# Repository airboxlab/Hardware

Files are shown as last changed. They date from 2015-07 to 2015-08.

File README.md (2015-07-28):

# Airboxlab Hardware
Documentation, electronics and mechanical CAD for Airboxlab

* Consult Bills of Materials available in this repo, for the diferent parts needed.
* Assembly instructions available in this repo in [html](https://cdn.rawgit.com/airboxlab/Hardware/master/Assembly_Instructions/assembly_instructions.html).
* Firmware documentation is in the [wiki](https://github.com/airboxlab/Firmware/wiki).

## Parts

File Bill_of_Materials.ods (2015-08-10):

Airboxlab Bill of Materials
 | Sub-assembly | Ref schematics | Qty | Part Description | Part Value | Package | Seeed PN | Replacement policy | Manufacturer | Manufacturer Ref | Notes/Remarks | Distributor | Second distributor | Third distributor
 | Sensor_PCB v2.1 | IC1 | 1 | I2C slave MCU | ATTiny24 | SOIC-14 |  | Ask | Atmel | ATTINY24A-SS |  | http://www.digikey.fr/product-search/fr?k=attiny24A-SS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 | http://fr.mouser.com/ProductDetail/Atmel/ATTINY24A-SSU/
 |  | J2 | 1 | Grove connector top SMD female |  | SMD | 3470090P1 | Ask
 |  | C1,C2,C3 | 3 | Decoupling capa | 1uF | C0805 | 0100440P1 | Similar
 |  | R1 | 1 | Resistor array | 4x 10k | R1206-8 | 0040070P1 | Similar
 |  | Q1 | 1 | Low side switch MOSFET | NMOS | SOT-23 | 0440200P1 | Similar
 |  | S1 | 1 | VOC Sensor |  |  |  | No | AppliedSensor | IAQEngine
 |  | S2 | 1 | CO2 Sensor |  |  |  | Ask |  | MQ135
 | Main_PCB v2.2 | IC1 | 1 | Humidity and temperature sensor I2C | CC2D23 | QFN-8 |  | No | GE M&C / NovaSensor | CC2D23 |  | http://fr.mouser.com/ProductDetail/GE-MC-NovaSensor/CC2D23/
 |  | U4 | 1 | Accelerometer | MMA8453 | QFN-16 |  | Ask | Freescale Semiconductor | MMA8453QT |  | http://fr.farnell.com/freescale-semiconductor/mma8453qt/accelerometer-10-8bit-3axis-16qfn/dp/1842361 | http://www.digikey.fr/product-search/fr?x=-1307&y=-73&lang=fr&site=fr&KeyWords=MMA8453QT
 |  | U2 | 1 | MCU with ADC, I2C, UART and USB | ATMega32u4 | QFN-44 |  | Ask | Atmel | ATMEGA32U4-MU |  | http://www.digikey.fr/product-detail/fr/ATMEGA32U4-MU/ATMEGA32U4-MU-ND/1914603 | http://fr.mouser.com/ProductDetail/Atmel/ATMEGA32U4-MU/?qs=sGAEpiMZZMvqv2n3s2xjsYzXfq0AWv1CDyO98lAu02M%3d
 |  | X1 | 1 | Crystal oscillator | 16MHz | QFN-2 | 0500290P1 | Similar
 |  | C4,C5 | 2 | Crystal oscillator capa | 8pF | C0603 |  | Similar |  | - |  | whatever | http://fr.farnell.com/jsp/search/productdetail.jsp?id=1759051&Ntt=1759051
 |  | U3 | 1 | USB ESD protection |  | SOT-23-6 |  | Ask | NXP Semiconductors | IP4220CZ6,125 |  | http://fr.farnell.com/nxp/ip4220cz6/esd-protection-dual-usb-2-0-6tsop/dp/1506629 | http://www.digikey.fr/scripts/DKSearch/dksus.dll?Detail&itemSeq=137462905&uq=635163209385322191
 |  | R4,R5 | 2 | USB resistors | 22R | R0603 | 0010010P1 | Similar
 |  | J1 | 1 | USB Micro plug |  | SMD | 3400150P1 | Similar
 |  | U1 | 1 | Battery charger chip |  | DFN-8 | 1320040P1 | Ask
 |  | J2 | 1 | Battery connector |  | THT | 3410070P1 | Ask |  |  |  |  | http://www.digikey.fr/product-search/fr?WT.z_header=search_go&lang=fr&site=fr&x=0&y=0&formaction=on
 |  | R1,R15,R16 | 3 | Rset, I2C pull ups | 3.6k 1% | R0603 |  | Similar |  | - |  | whatever | http://fr.mouser.com/Search/ProductDetail.aspx
 |  | (K1) | 0 | Reset button |  |  | 3100010P1 | Similar
 |  | L2,L5 | 2 | ferrite bead | 120R 500mA | L0603 | 0040070P1 | Similar
 |  | F1 | 1 | Fuse 1000mA | 1000mA | R1206 | 0900020P1 | Similar
 |  | IC3 | 1 | step-up reg 5V | 5V, >=500mA | TSOP-5 |  | Ask | ON Semiconductor | NCP1450ASN50T1G |  | http://fr.farnell.com/on-semiconductor/ncp1450asn50t1g/convertisseur-dc-dc-step-up-5-0v/dp/1460676
 |  | Q1,Q3 | 2 | MOSFET N channel | NMOS | SOT-23 | 0440200P1 | Similar
 |  | D1 | 1 | Shottky diode | 5A | SMB | 0310130P1 | Similar
 |  | L1 | 1 | Inductor | 10uH |  |  | Similar | Bourns | SRU8043-100Y |  | http://fr.farnell.com/bourns/sru8043-100/inductance-de-puissance-blindee/dp/1362119
 |  | C14,C15,C28,C29,C31 | 5 | Capa Tantalum | 100uF | AVX-C | 0130170P1 | Similar
 |  | U5 | 1 | 3.3V regulator | 3.3V, 1A | SOT-89 | 1310120P1 | Similar
 |  | U6 | 1 | Wifi module | CC3000 | QFN |  | No | Texas Instruments | CC3000MOD |  | http://www.digikey.fr/product-search/fr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 | http://fr.mouser.com/ProductDetail/Texas-Instruments/CC3000MOD/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
 |  | ANT1 | 1 | Chip Antenna 2,4GHz | 2,4GHz |  |  | No | Johanson Technology Inc | 2450AT42A100E |  | http://fr.farnell.com/johanson-technology/2450at42a100e/antenne-2-4ghz/dp/2148522 | http://fr.mouser.com/ProductDetail/Johanson/2450AT42A100E/ | http://www.digikey.com/product-detail/en/2450AT42A100E/712-1007-1-ND/1560836
 |  | Q2,Q4,Q5,Q6,Q7 | 5 | Drivers for LEDs, P-channel MOSFET | PMOS | SOT-23 | 0440210P1 | Similar
 |  | D3,D4 | 2 | RGB Led |  | THT |  | Ask | Kingbright Company LLC | WP154A4SUREQBFZGW |  | http://fr.mouser.com/ProductDetail/Kingbright/WP154A4SUREQBFZGW/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
 |  | JP2 | 1 | GP2Y cable connector top insertion | 6 pin | THT |  | Ask | JST | B6B-ZR (LF)(SN) |  | http://www.digikey.fr/product-detail/fr/B6B-ZR(LF)(SN)/455-1661-ND/926568 | http://fr.farnell.com/jst-japan-solderless-terminals/b6b-zr-lf-sn/embase-entree-sup-6-voies/dp/9491805
 |  | R7,R8,R9,R10,R11,R12 | 6 | resistor for LEDs | 75R | R0603 | 0010220P1 | Similar |  |  |  |  | http://fr.mouser.com/ProductDetail/Vishay-Dale/CRCW060375R0FKEA/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
 |  | J3 | 1 | Grove connector top SMD female |  |  | 3470090P1 | Ask
 |  | D2,D5,D6 | 3 | Shottky / Flyback diode | 1A | SOD-123 | 0390030P1 | Similar |  |  |  |  | http://fr.mouser.com/ProductDetail/ON-Semiconductor/MBR130LSFT1G/
 |  | JP3 | 1 | Connector for Fan |  | THT |  | Ask | JST | B2B-XH-A (LF)(SN) |  | http://fr.farnell.com/jst-japan-solderless-terminals/b2b-xh-a-lf-sn/embase-male-vertical-2-voies/dp/1516276 | http://www.digikey.com/product-detail/en/B2B-XH-A%20(LF)(SN)(P)/455-2247-ND/1651045
 |  | C1,C2,C12,C13,C16,C17,C21 | 7 | Capa | 10uF | C0805 | 0100080P1 | Similar
 |  | C3,C6,C7,C8,C9,C10,C11,C19,C20,C23 | 10 | Capa | 1uF | C0603 | 0100340P1 | Similar
 |  | C18,C22,C24,C25,C26,C27 | 6 | Capa | 0,1uF | C0603 | 0100020P1 | Similar
 |  | S1 | 1 | ON/OFF switch |  | THT |  | Ask | C & K COMPONENTS | OS102011MA1QN1 |  | http://fr.farnell.com/c-k-components/os102011ma1qn1/emission-laterale-commutateur-spdt/dp/1201431
 |  | R2,R6,R13,R14 | 4 | Pull up/ pull down / voltage dividers | 10k x4 | R1206-8 |  | Similar |  | - |  | whatever | http://fr.mouser.com/ProductDetail/CTS-Electronic-Components/742C083473JP/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
 |  | (R3),R17,(R18) | 1 | Temp sensor power select, ([ALT]short 5V_switched and 5V_dirty) | 0R | R0603 |  | Similar |  | - |  | whatever
 |  | R19 | 1 | Isolation resistor for ADC | 100k | R0603 |  | Similar |  | - |  | whatever
 | GP2Y cable |  | 2 | Housing |  |  |  | No | JST | ZHR-6
 |  |  | 12 | Contact |  |  |  | No | JST | SZH-002T-P05 or SZH-003T-P05
 |  |  | 6 | Wire | 26 to 32 AWG, smaller the better |  |  | Similar
 |  |  |  | The GP2Y cable is straight (pin 1 is connected to pin 1) and flat (wires are not twisted). Both ends have the same connector.
 |  |  |  | Length from end of connector to end of connector : 33mm +/- 5mm
 |  |  |  | Preferably ribbon if possible
 |  |  |  | No requirement on wire colors
 | Grove Cable |  | 2 | Housing | buckled |  |  | Ask
 |  |  | 8 | Contact | like Grove cables |  |  | Similar
 |  |  | 4 | Wire | like Grove cables |  |  | Similar
 |  |  |  | The Grove Cable is straight (pin 1 is connected to pin 1) and flat (wires are not twisted). Both ends have the same connector.
 |  |  |  | Length from end of connector to end of connector : 135mm +/- 5mm
 |  |  |  | No requirement on wire colors
 | Enclosure | Cylinder_v13.igs | 1 | Tube |  |  |  | Ask
 |  | Top_plate.igs | 1 | Top plate |  |  |  | Ask
 |  | Bottom_part.stl | 1 | Bottom part |  |  |  | Ask | Sculteo / Shapeways |  | white strong and flexible | http://www.shapeways.com/product/HX6P2HMSU/airboxlab-pusher?li=user-profile&optionId=15531137
 |  | Pusher.stl | 2 | Pusher |  |  |  | Ask | Sculteo / Shapeways |  | white strong and flexible | http://www.shapeways.com/product/XN6GGS49G?li=user-profile&optionId=15530376
 |  | Top_cap.stl | 1 | Top cap |  |  |  | Ask | Reprap |  | white ABS / PLA
 |  | All_parts_but_bottom.svg | 1 | All laser cutted part |  |  |  | Ask | Lasercut |  | clear PMMA
 |  | Bottom_plate_white.svg | 1 | Bottom plate |  |  |  | Ask | Lasercut |  | white PMMA
 |  |  | 4 | Rubber feets |  |  |  | Similar | 3M | SJ5382 | clear | http://www.by-pixcl.com/3m-butees-adhesives-bumpon,fr,8,181.cfm
 |  |  | 4 | Bottom screws |  |  |  | Similar |  |  |  | http://www.visseriefixations.fr/plastite-tf-pozi-3x10-z-blanc.html
 |  |  | 4 | Side plates screws |  |  |  |  |  |  |  | http://www.visseriefixations.fr/voir-platcbh02-2-008zn.html
 |  |  | 4 | PCB & Pusher screws |  |  |  |  |  |  |  | http://www.visseriefixations.fr/tcbl-pozi-m2x6-z-blanc-din-7985.html

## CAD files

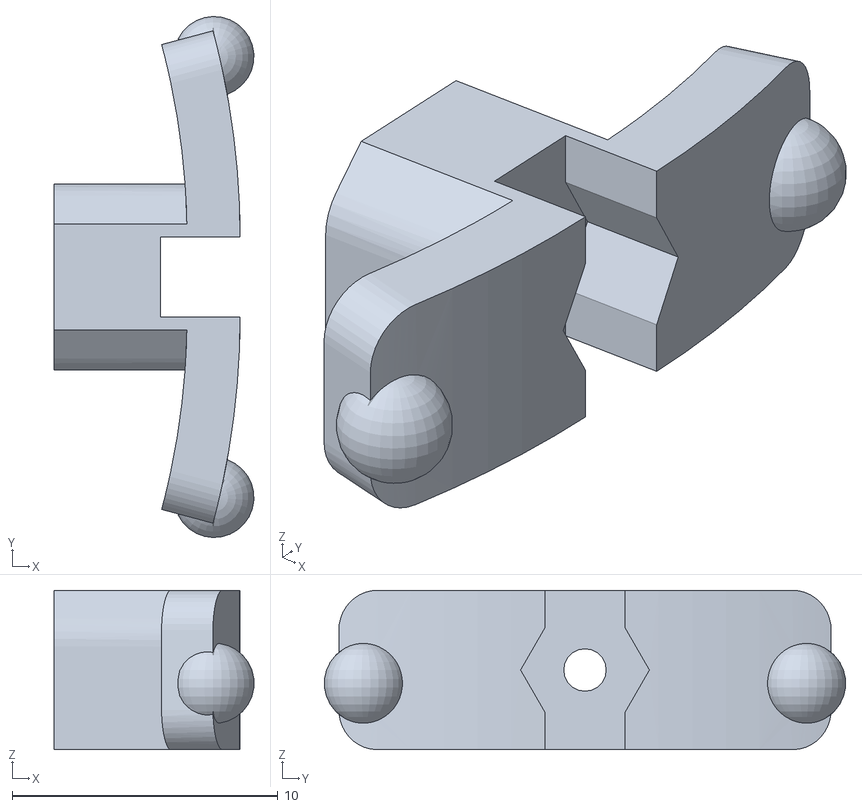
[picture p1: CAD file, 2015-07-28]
Mechanical_CAD/3D_printed/Pusher.stl
7.52 x 19.6 x 6.00

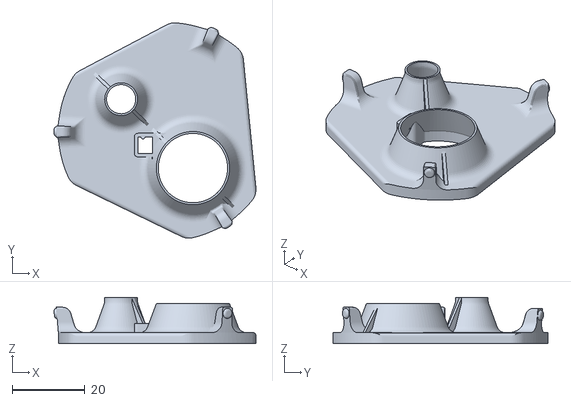
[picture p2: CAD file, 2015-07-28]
Mechanical_CAD/3D_printed/Top_cap.stl
55.4 x 59.1 x 12.7

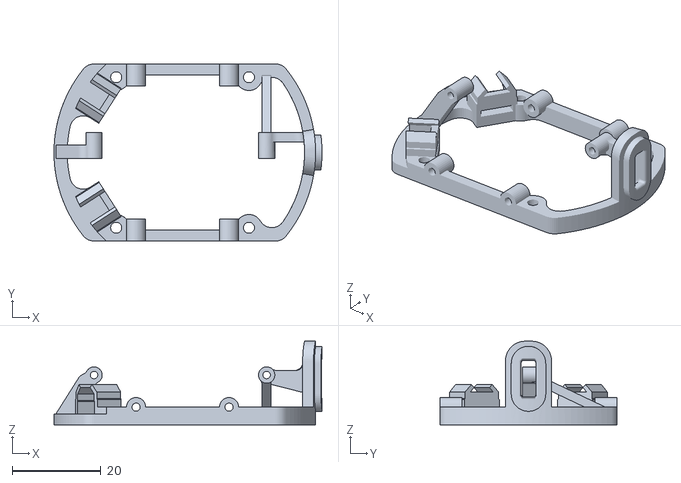
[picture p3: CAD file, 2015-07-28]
Mechanical_CAD/3D_printed/Bottom_part.stl
60.5 x 40.0 x 18.9

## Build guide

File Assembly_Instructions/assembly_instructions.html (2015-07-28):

Assembly Instructions

Airboxlab – Indoor air quality monitor (http://airboxlab.foobot.io)

This work by Airboxlab S.A. (http://airboxlab.com) is licensed under CERN OHL v. 1.2 (http://ohwr.org/cernohl).

Index table

1 Introduction

2 Required tools and supplies

2.1 Tools

2.2 Supplies

3 Prepare parts

3.1 Top_cap

3.2 Bottom_part

3.3 Pushers

3.4 Bottom_cap

4 Assembly steps

# 1 Introduction

This document describes Airboxlab indoor air quality manual step by step. It mandatory to follow the instruction in the described order for a compelling result.

Part names that this document refers to match the ones of the mechanical CAD.

# 2 Required tools and supplies

## 2.1 Tools

- Secondary M2 tap
- Small electric screw driver
- Pozidrive #1 screw bit
- Small Pozidrive #1 screw driver with a rod no lager than 3mm. Alternate: flat 2mm screw driver.
- Scalpel with pointed sharp ending blade
- Flat elongated pliers (no teeth) to handle connectors
- 6mm metal drill bit
- Pair of cisors
- Wire cutters
- Glue gun, No silicone based glue (fumes will damaged sensors)
- Drill Press

## 2.2 Supplies

Quantity to assemble one unit.

- 4x oval head machine screws POZI 2x6mm
- 4x thermoplastic domed head screws POZI 2.2x8mm
- 4x countersunk flathead thermoplastic screws POZI 3x10mm
- 2x Zip-tie 2.5x200mm
- 4x transparent silicone pads
- Electrical tape (~ 25cm)
- Transparent office tape (~ 15cm)
- Double-sided tape (~ 2cm)

# 3 Prepare parts

## 3.1 Top_cap

- Check hole in top cap to insert pin, correct hole with scalpel if necessary. Add a glue blob on each side of the pin.
   

## 3.2 Bottom_part

- Optional if the 2 POZI M2x6 do not hold when using the electrical screw driver: M2 tapping the two holes for the PCB.

## 3.3 Pushers

- Optional if the 2 POZI M2x6 do not hold when using the electrical screw driver: M2 tapping the two holes.
- Screw an M2x6 screw from the side with the fins until flush on the flat side:



## 3.4 Bottom_cap

- Countersink 4 holes with drill 6mm metal, plastic film side, of sufficient depth so that POZI 3x10 screw heads are fully embedded:
  
- Deburring with scalpel if necessary.

# 4 Assembly steps

1. Prepare parts (see 3).
2. Glue a piece of electrical tape over the battery, on the side where there is nothing written.
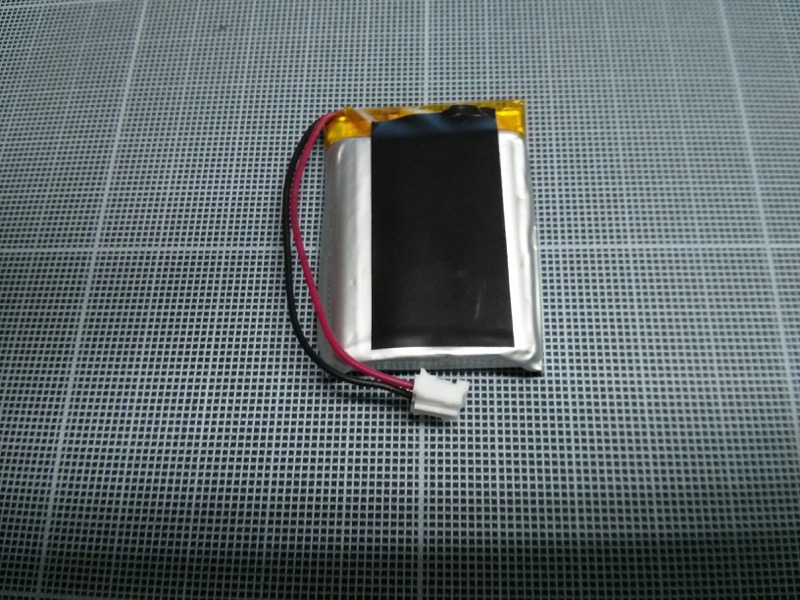
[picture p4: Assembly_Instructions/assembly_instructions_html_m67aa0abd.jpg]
  
3. Attach the battery on the side_plate with electrical tape, making sure of the orientation:
- Side of the battery with electrical tape is against side_plate.
- Battery is about 5mm above the bottom of the side_plate holes.
- Battery's wire comes down on the same side that the notches for the wires.

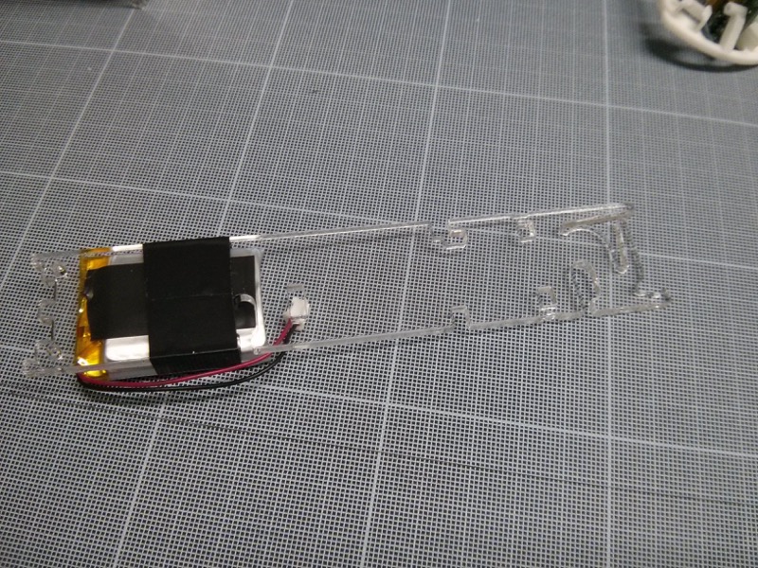
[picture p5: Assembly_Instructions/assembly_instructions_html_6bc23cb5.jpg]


3. Screw Main_PCB on bottom_part with 2 POZI M2x6 screws
  
4. Insert the two pushers in there notches in bottom_part.
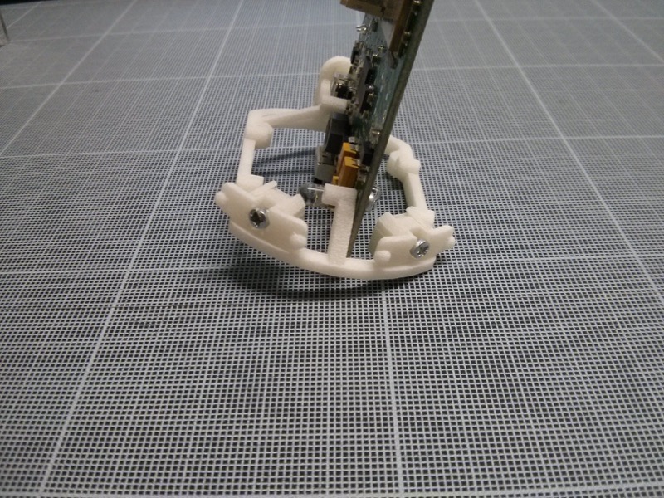
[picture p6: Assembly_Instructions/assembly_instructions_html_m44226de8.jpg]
  
5. Attach the fan and its two supports with two zip-tie (all together this is the top cross_section of airboxlab). Make sure of the orientation of parts: fan airflow direction, fan wire and zip-tie.
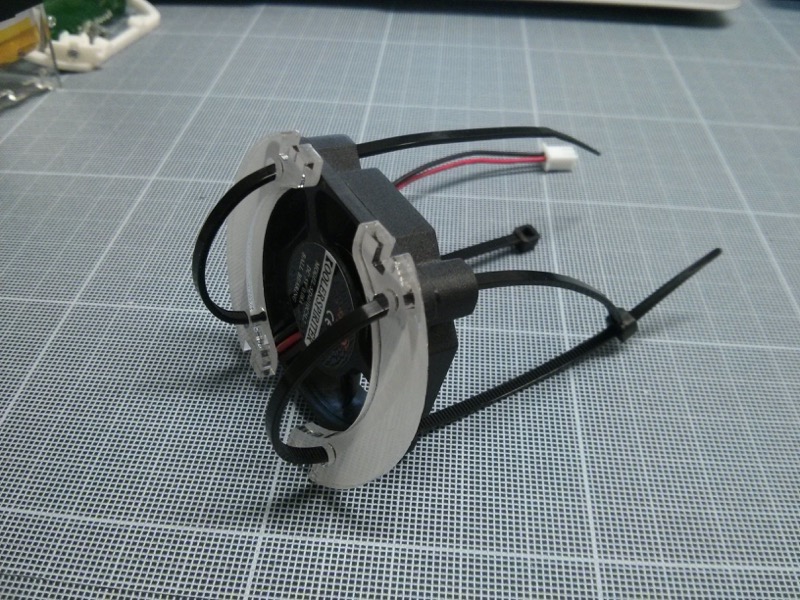
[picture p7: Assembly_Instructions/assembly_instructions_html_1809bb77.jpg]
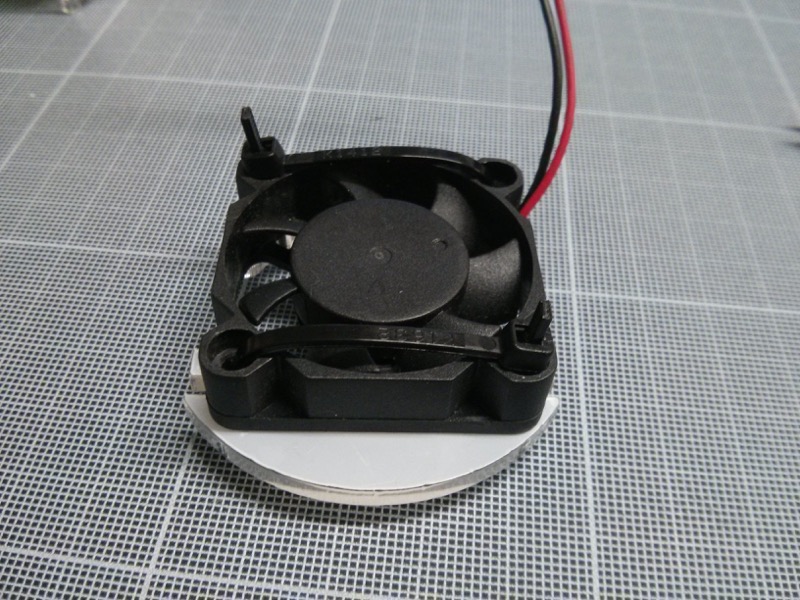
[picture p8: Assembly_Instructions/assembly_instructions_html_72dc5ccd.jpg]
   
6. Glue GP2Y on middle cross_section. Use a tool to precisely align it, if alignment is wrong it won't enter properly.
  
7. Connect GPY2 cable in the sensor then into Main_PCB.
  
8. Insert the assembly consisting of Main_PCB + bottom_part in the groove of the bottom cross_section. Check alignment with bottom_part: the sides of bottom_part must be aligned with sides of the cross_section.
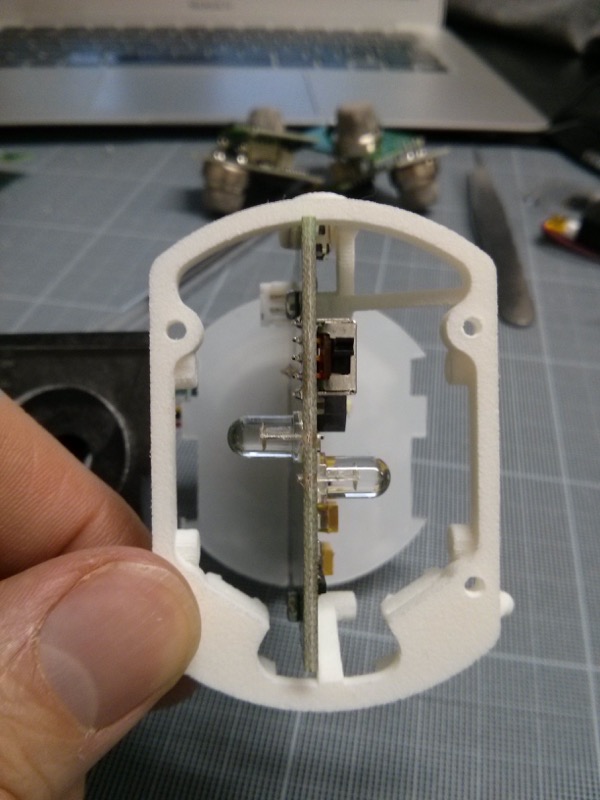
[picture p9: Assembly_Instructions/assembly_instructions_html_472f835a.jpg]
   
9. Assemble the 3 cross_sections on side_plate to which is attached the battery, starting with the one with the fan.
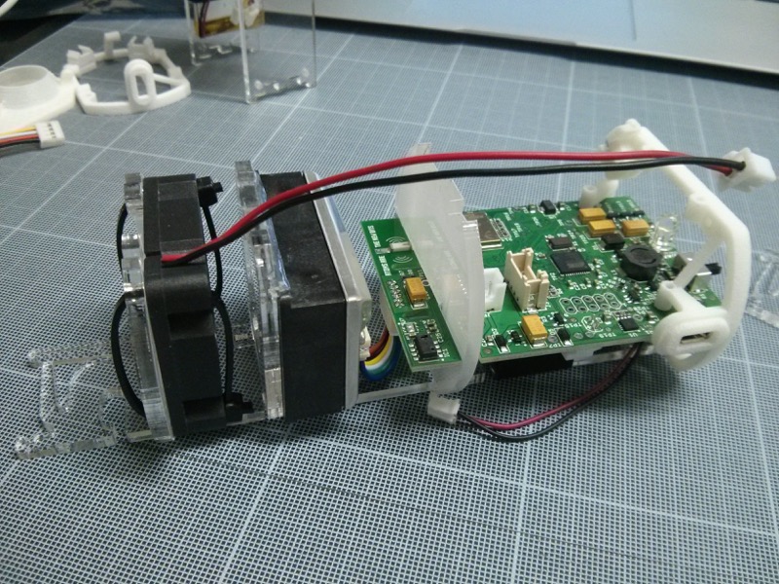
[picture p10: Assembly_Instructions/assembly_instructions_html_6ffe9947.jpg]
  
10. Place the second side_plate over the whole assembly. Both side_plates must be oriented so as to be superimposed. Check that the fan cable goes well in his small notch at the middle cross_section.
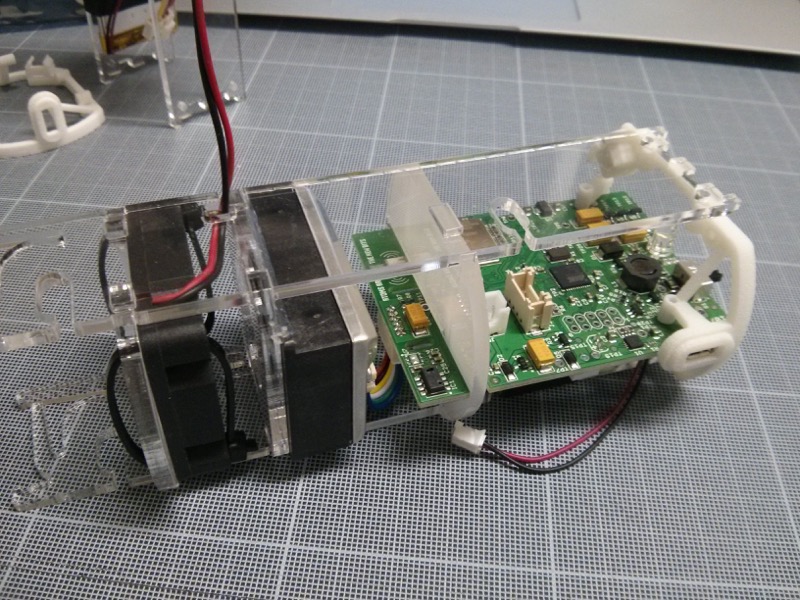
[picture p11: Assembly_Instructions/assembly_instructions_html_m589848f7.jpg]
  
11. Check that the sections are fully engaged, especially the middle one.
12. Put a strip of electrical tape (> = 16.5 cm) around the fan and the middle section:
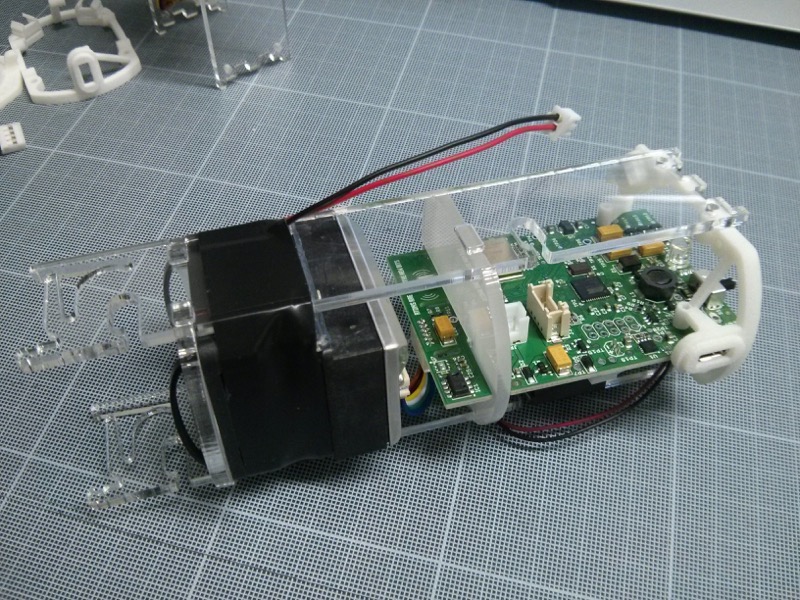
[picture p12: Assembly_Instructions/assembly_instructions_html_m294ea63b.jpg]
  
13. Connect Grove cable on Sensor_PCB.
14. Clip Sensor_PCB in the side plates and pass Grove cable into its top notch.
  
15. Place fan cable then Grove cable into the bottom cable notch.
16. Connect the fan cable in the Main_PCB using flat pliers.
17. Plug the cable into the Grove Main_PCB using flat pliers.
18. Pull excess wire with pliers so that they are snug to the side_plate.
19. Tape both cables on side_plate (~ 6cm).
  
20. Ensure that Main_PCB is totally engaged in the groove of cross_section, so that the edge of the PCB with T/RH sensor is flush along the cross_section.
21. Screw the side_plates to the bottom_part with 4 thermoplastic POZI 2.2x8mm screws.
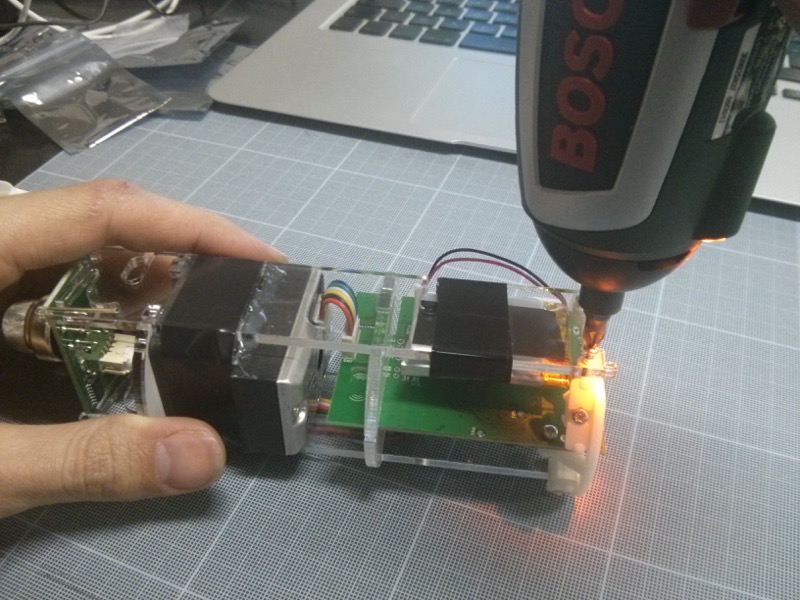
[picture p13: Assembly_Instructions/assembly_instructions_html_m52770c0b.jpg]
  
22. Connect the battery.
  
23. Insert the whole assembly into the enclosure with LED and USB connector up. Press on the cylinder to modify its roundness so to get the USB into its designated hole.
  
24. Place the Roundifiers, cut corners towards the Pushers.
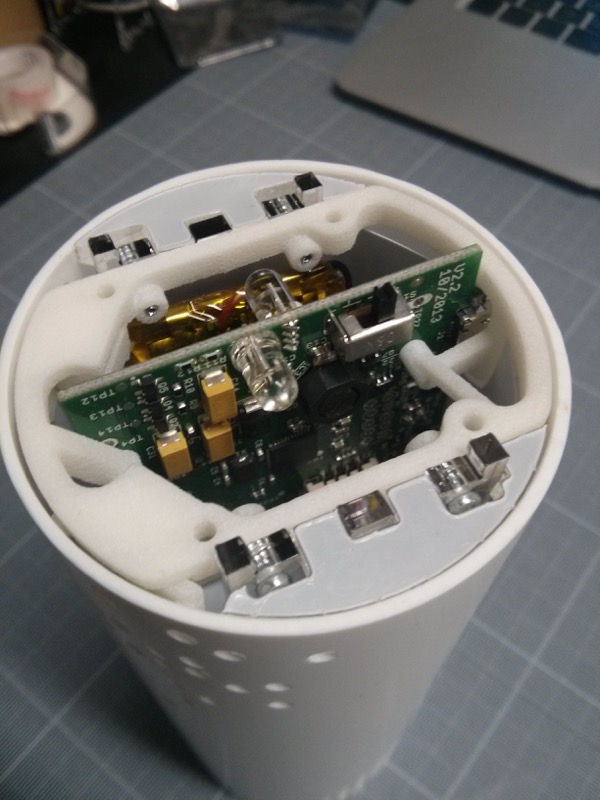
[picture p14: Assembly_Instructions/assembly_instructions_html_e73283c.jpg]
  
25. Insert led_pipe disc then the bottom_plate and screw the two together with the 4 3x10mm thermoplastic countersunk screws.
  
26. Glue the 4 transparent silicone pads.
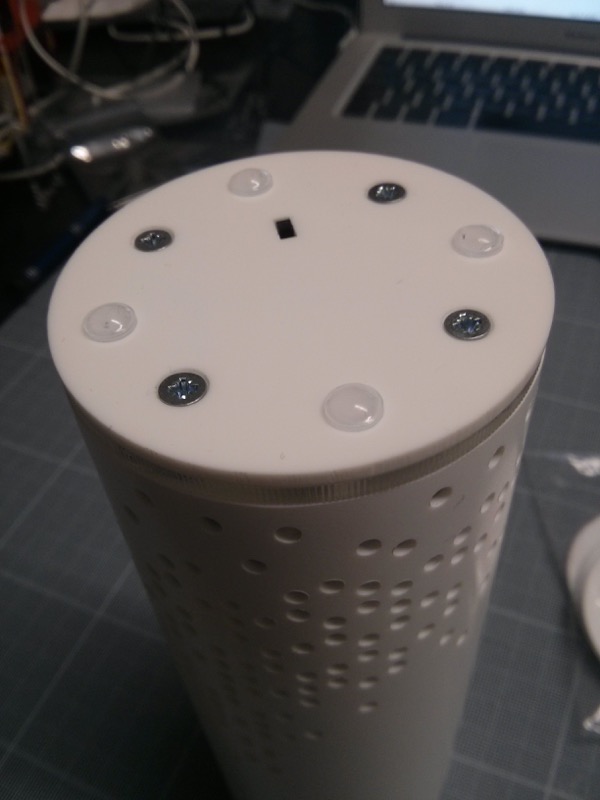
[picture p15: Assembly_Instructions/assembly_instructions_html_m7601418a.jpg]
  
27. Clip the top_cap with pin fitting into the Sensor_PCB's hole to center the inner assembly.
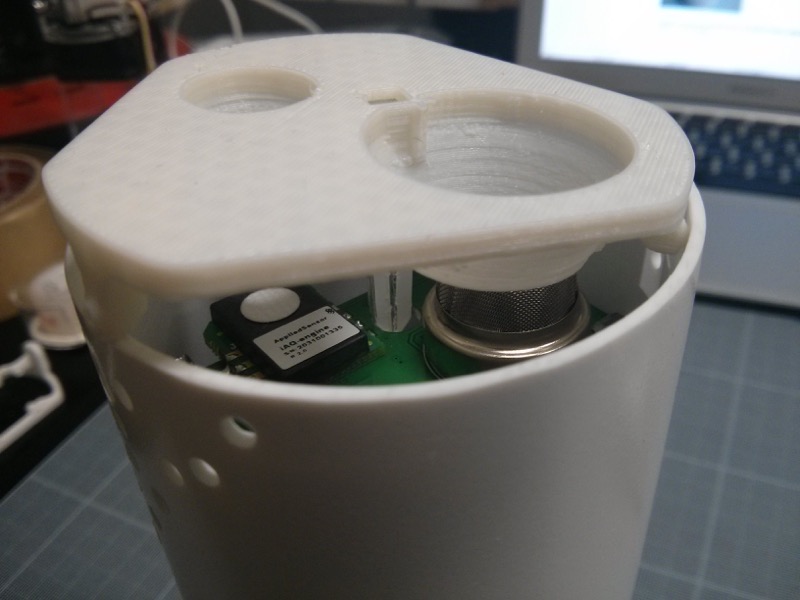
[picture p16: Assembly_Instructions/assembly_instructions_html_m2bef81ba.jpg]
  
28. Screw both Pushers until their nipples fit into the holes. The whole assembly should not move, but do not over-tight the screws otherwise the cylinder will misshapen and offset from the lower plates.
  
29. Stick two pieces of double-sided tape on the top_cap, remove the protective film and place the top_plate aligning the holes with the sensors. The plate must protrude about 0.5mm from the cylinder.
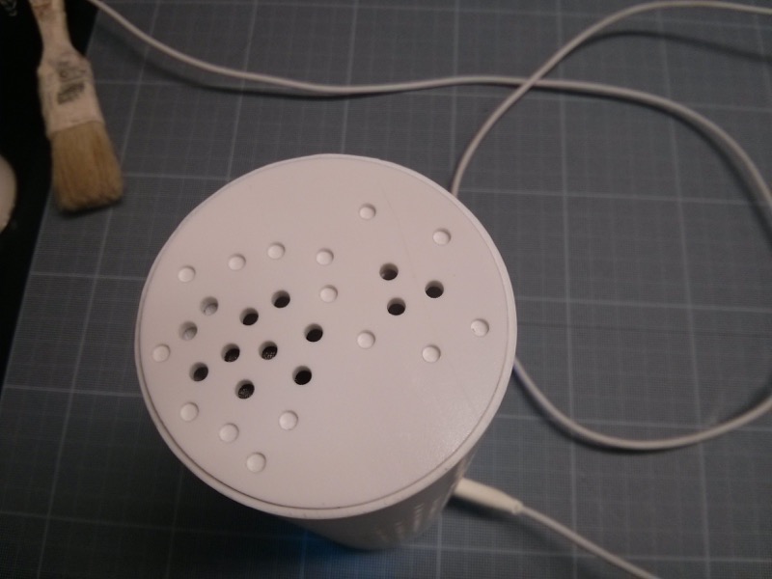
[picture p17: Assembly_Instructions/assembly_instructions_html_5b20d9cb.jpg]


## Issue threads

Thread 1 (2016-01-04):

Model / instructions for enclosure

arthurlutz, 2016-01-04:
Looking through the different parts, I cannot find any instructions on how to build or print the enclosure. Are the 3d printed parts stl files missing ? I can export stl files by opening AirBoxLab_v2_assembled.stp from FreeCAD but I'm not sure this is correct.

By the way when opening the stp (Catia ?) file in FreeCAD I get :

```
  Cannot compute Inventor representation for the shape of Part__Feature750.
```

If you drill the holes using a PVC tube bought in a hardware store, can you make a paper print out of the holes ?

airboxlab, 2016-01-05:
Hello. Have a look at the BOM you have some links to order the parts from shapeway. For the tube you should not use SLS printing but rather filament printing or as you mentioned an extruded tube.

Regarding your issue with FreeCAD did you try with another software? STP should be really easy to open in Solidworks or Catia.

arthurlutz, 2016-01-05:
Hi @airboxlab

Thanks for your reply. In the BOM there is a reference to Cylinder_v13.igs which doesn't seem to exist in the repo.

I'm happy to try another CAD software for AirBoxLab_v2_assembled.stp, as long as it's an open source software, that's why I didn't use Catia. I'm a bit new to this 3D CAD stuff, but would there be a more "standard"/open file format for those files that you could export from Catia to make it more accessible to those without a Catia licence ?

airboxlab, 2016-01-05:
cylinder_v13 is part of the assembly file provided in stp file format.

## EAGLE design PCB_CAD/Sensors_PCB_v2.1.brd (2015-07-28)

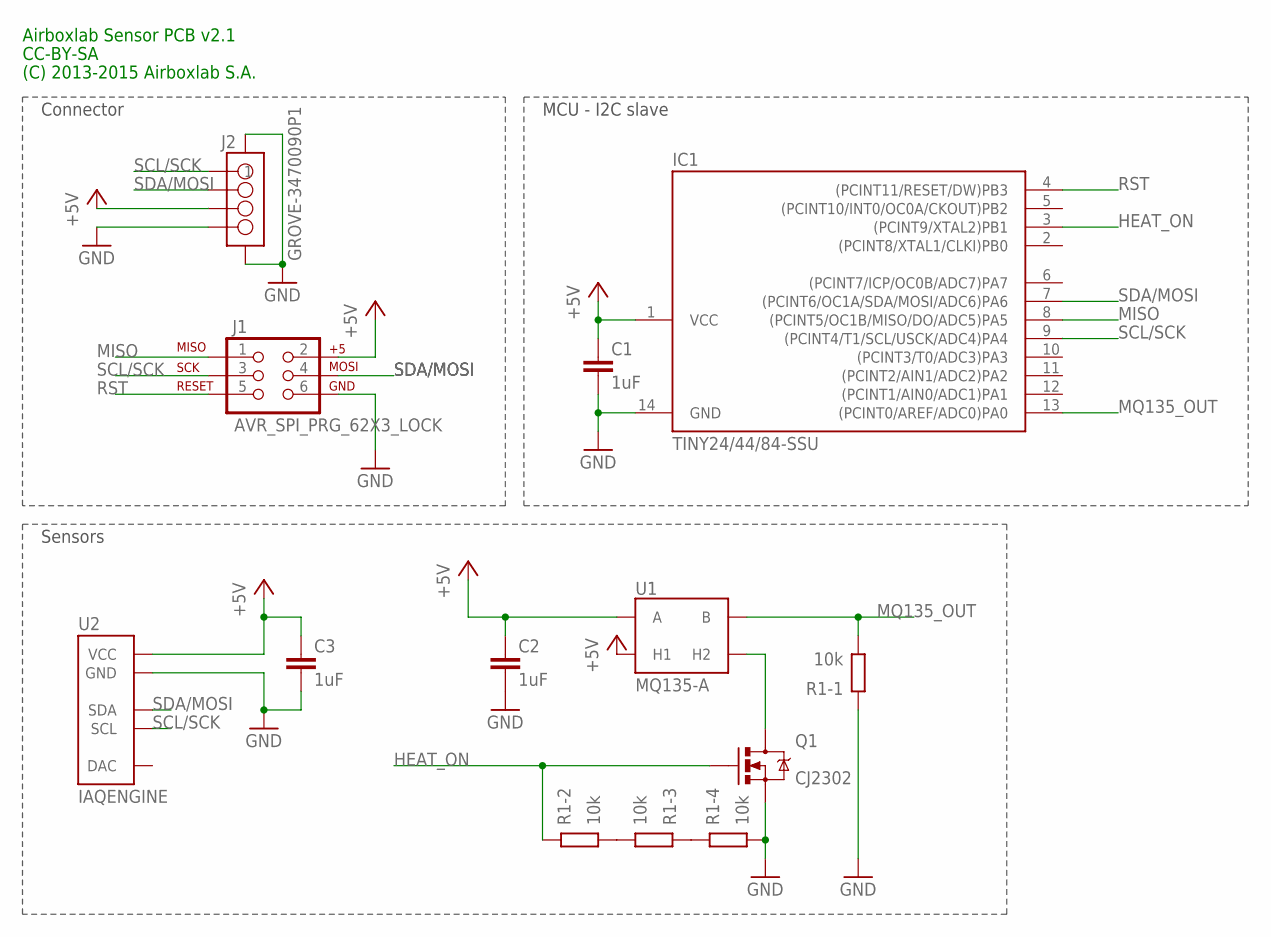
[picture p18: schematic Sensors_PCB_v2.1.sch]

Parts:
C1, C2, C3: 1uF; 0603_N
IC1: TINY24/44/84-SSU; SOIC14
J1: AVR_SPI_PRG_62X3_LOCK; 2X3_LOCK
J2: GROVE-3470090P1; 4P-SMD-2.0
Q1: CJ2302; SOT-23-3_N/SSOT-3_N
R1: 10k; R_0603_80P_4
U1: MQ135-A
U2: IAQENGINE

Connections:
+5V: C1.1, C2.1, C3.1, IC1.1 (VCC), J1.2, J2.3, U1.1 (A), U1.2 (H1), U1.3 (A), U2.6 (VCC)
GND: C1.2, C2.2, C3.2, IC1.14 (GND), J1.6, J2.4, J2.SS1, J2.SS2, Q1.2 (S), R1.4 (1), R1.8 (2), U2.3 (GND)
HEAT_ON: IC1.3 ((PCINT9/XTAL2)PB1), Q1.1 (G), R1.7 (2)
MISO: IC1.8 ((PCINT5/OC1B/MISO/DO/ADC5)PA5), J1.1
MQ135_OUT: IC1.13 ((PCINT0/AREF/ADC0)PA0), R1.1, U1.4 (B), U1.6 (B)
unnamed: R1.5 (2), R1.6 (2)
unnamed: R1.2 (1), R1.3 (1)
unnamed: Q1.3 (D), U1.5 (H2)
RST: IC1.4 ((PCINT11/RESET/DW)PB3), J1.5
SCL/SCK: IC1.9 ((PCINT4/T1/SCL/USCK/ADC4)PA4), J1.3, J2.1, U2.2 (SCL)
SDA/MOSI: IC1.7 ((PCINT6/OC1A/SDA/MOSI/ADC6)PA6), J1.4, J2.2, U2.4 (SDA)

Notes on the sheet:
Sensors
Connector
MCU - I2C slave
(C) 2013-2015 Airboxlab S.A.
CC-BY-SA
Airboxlab Sensor PCB v2.1

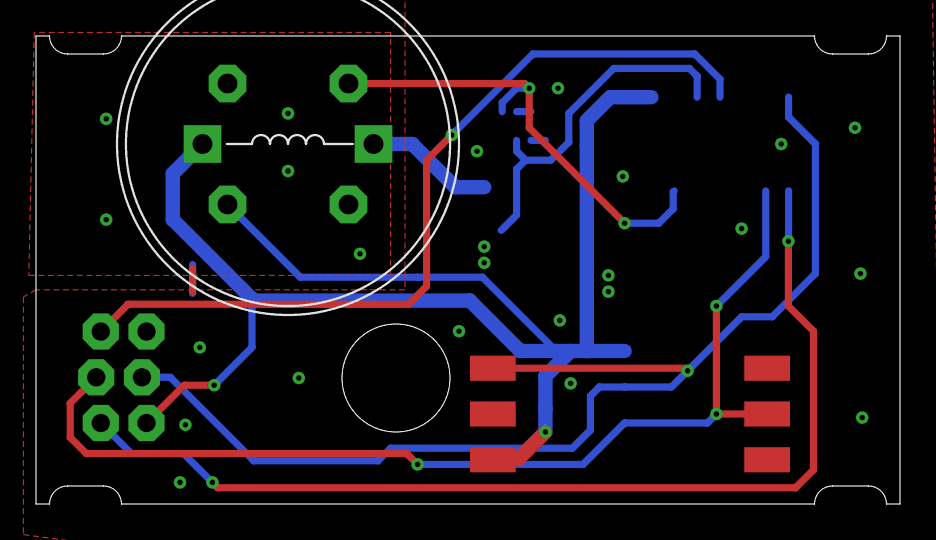
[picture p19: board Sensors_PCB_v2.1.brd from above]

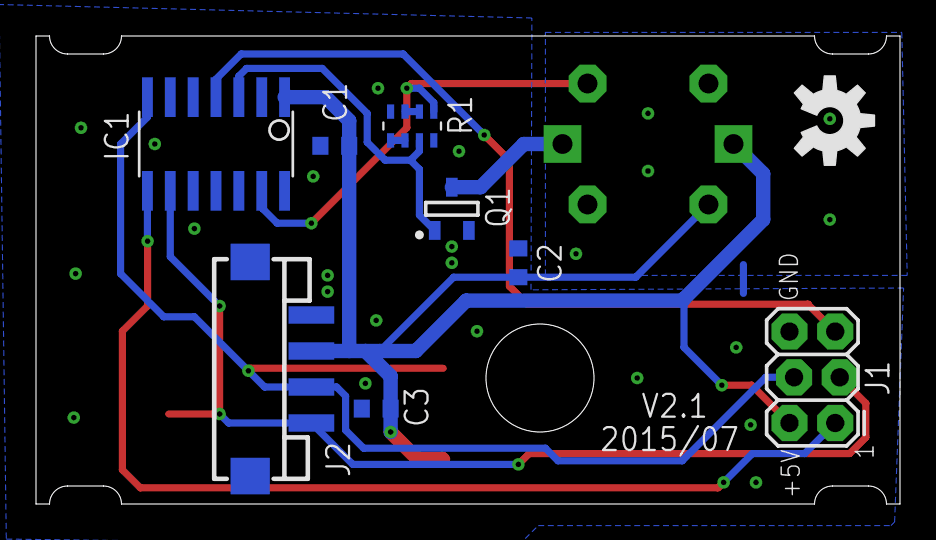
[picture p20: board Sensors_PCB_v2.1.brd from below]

Board: 2 copper layers, 48.0 x 26.0 mm, 11 parts (9 on the bottom side), 11 nets.

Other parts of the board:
U$1: OSHW-LOGO-M

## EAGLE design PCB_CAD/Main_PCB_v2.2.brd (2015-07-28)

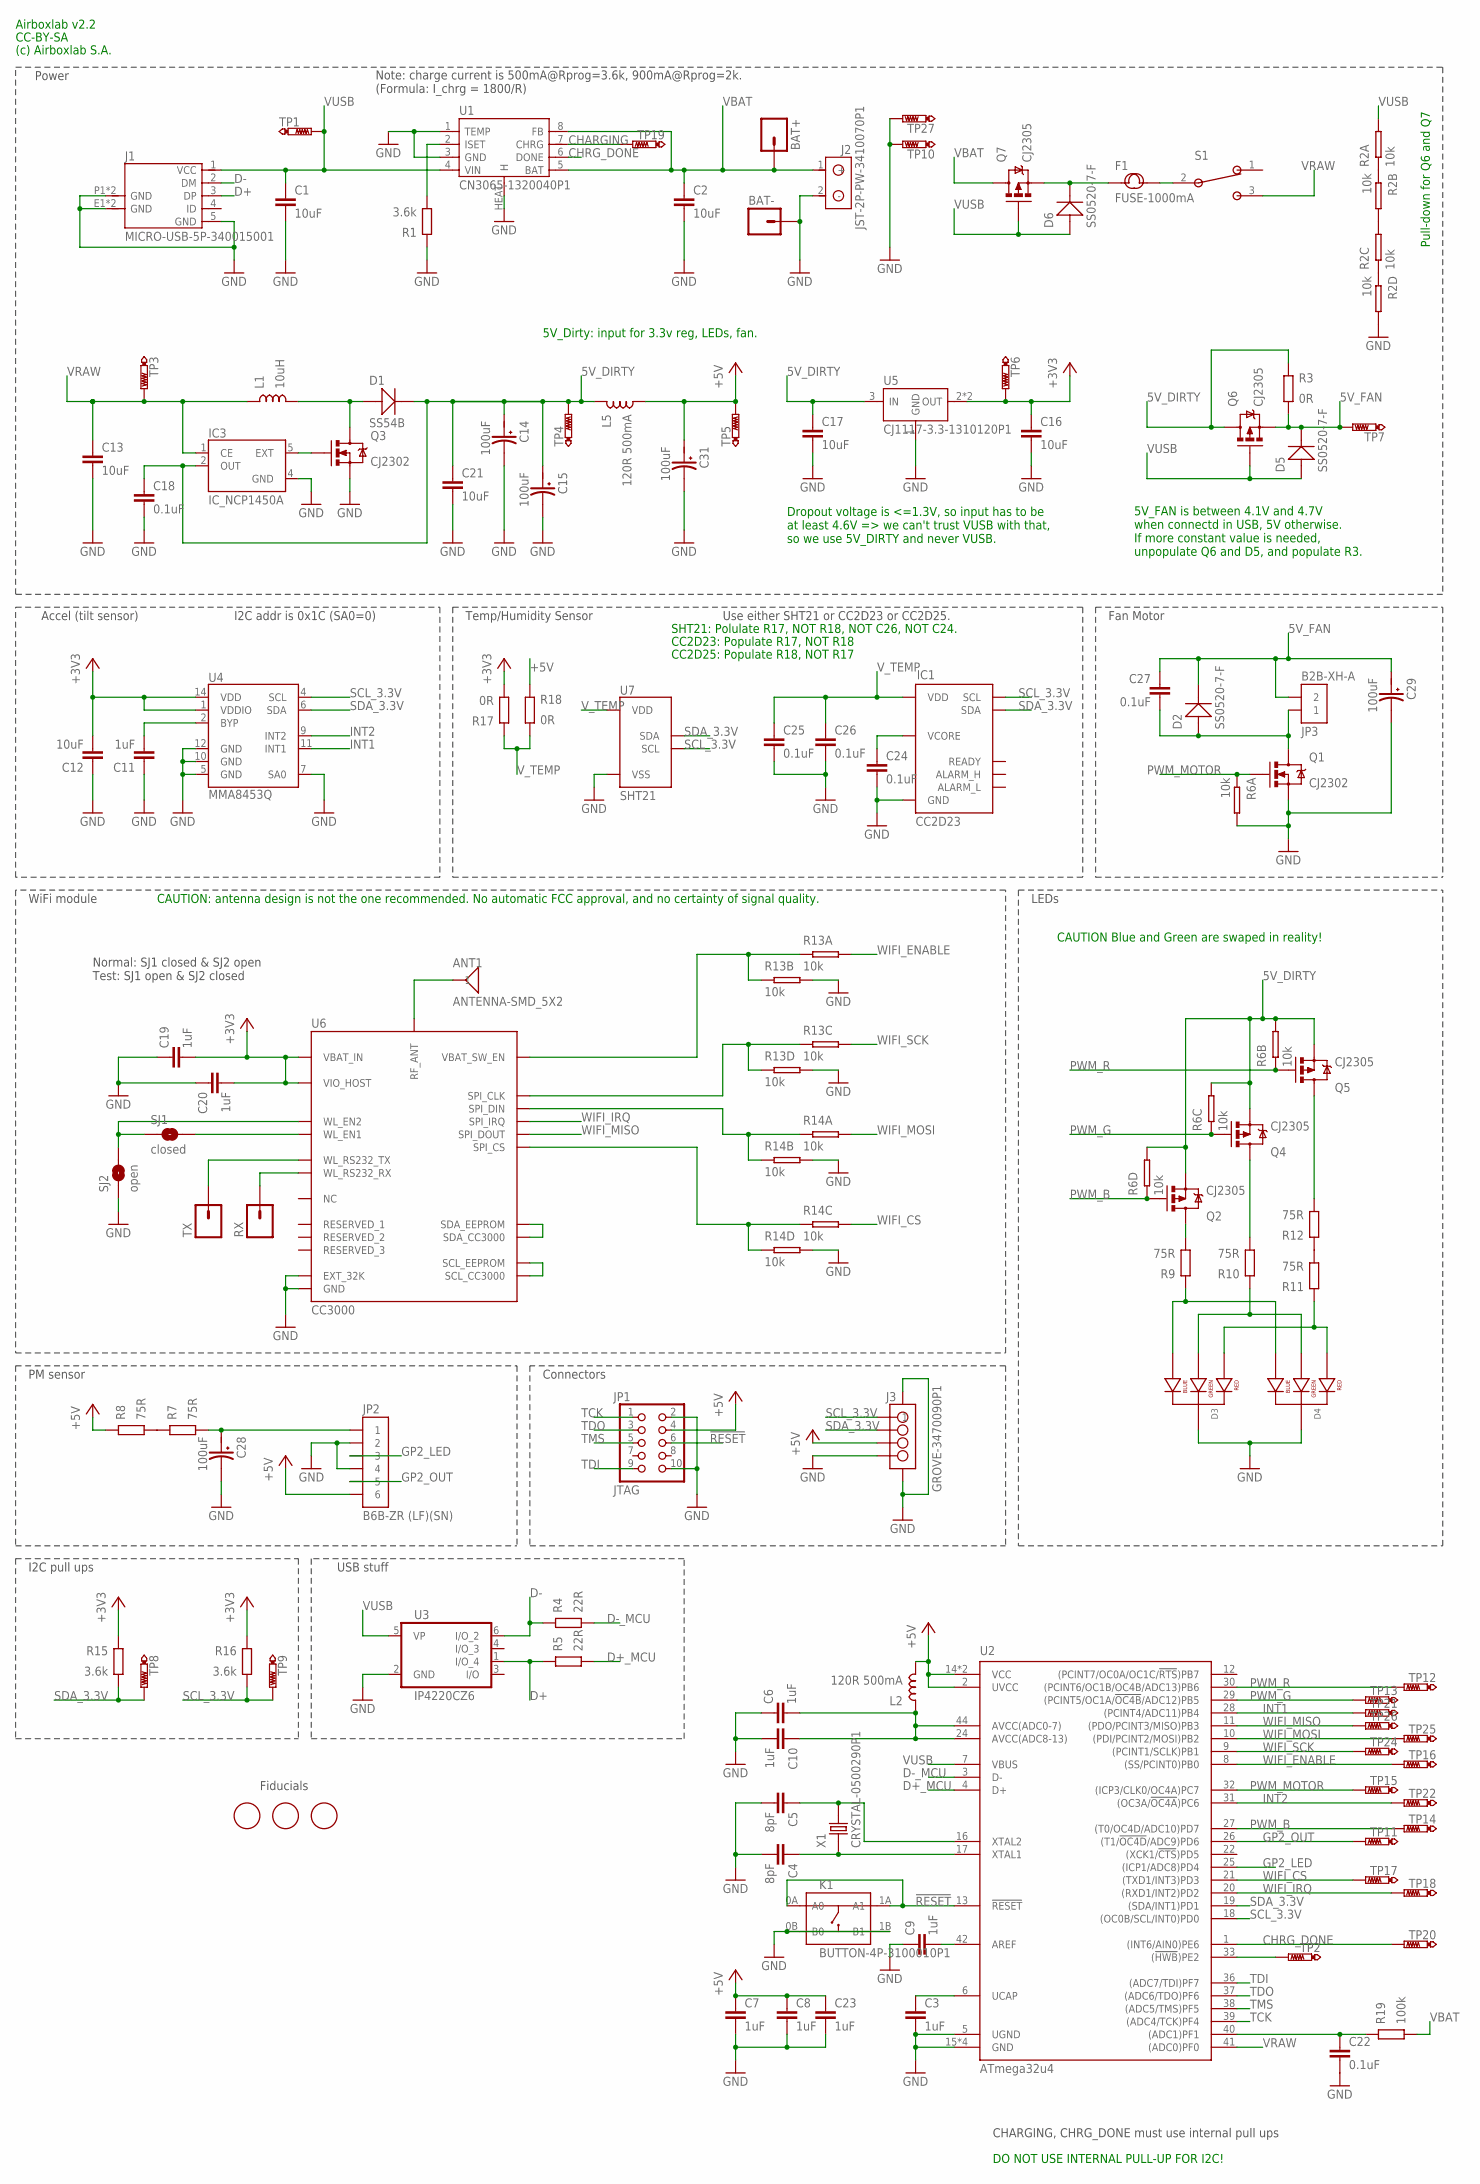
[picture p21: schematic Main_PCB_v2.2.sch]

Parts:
ANT1: ANTENNA-SMD_5X2; ANTENNA_SMD_5X2
BAT+: M01PTH; 1X01
BAT-: M01PTH; 1X01
C1, C2, C12, C13, C16, C17, C21: 10uF; 0805_N
C3, C6, C7, C8, C9, C10, C11, C19, C20, C23: 1uF; 0603_N
C4, C5: 8pF; 0603_N
C14, C15, C28, C29, C31: 100uF; AVX-C
C18, C22, C24, C25, C26, C27: 0.1uF; 0603_N
D1: SS54B; SMB
D2, D5, D6: SS0520-7-F; SOD123
D3, D4: LED-RGB-CC-THRUCLEAR; LED-RGB-THRU
F1: FUSE-1000mA; F1206
IC1: CC2D23; CC2DXX
IC3: IC_NCP1450A; SOT-23-5_N
J1: MICRO-USB-5P-340015001; B-SMD-5P
J2: JST-2P-PW-3410070P1; 2P-2.0-90D
J3: GROVE-3470090P1; 4P-SMD-2.0
JP1: JTAG; CONNECTOR_2.54MM_5X2_LOCK
JP2: B6B-ZR (LF)(SN); CONNECTOR_B6B-ZR
JP3: B2B-XH-A; CONNECTOR_B2B-XH-A
K1: BUTTON-4P-3100010P1; 4P-SMD-6.0X6.0X5.0H
L1: 10uH; L_SRU8043
L2, L5: 120R 500mA; 0603_N
Q1, Q3: CJ2302; SOT-23-3_N/SSOT-3_N
Q2, Q4, Q5, Q6, Q7: CJ2305; SOT-23-3_N/SSOT-3_N
R1, R15, R16: 3.6k; 0603_N
R2, R6, R13, R14: 10k; R1206-8
R3, R17, R18: 0R; 0603_N
R4, R5: 22R; 0603_N
R7, R8, R9, R10, R11, R12: 75R; 0603_N
R19: 100k; 0603_N
RX: M01PTH; 1X01
S1: SWITCH_SPDT_ON-ON; SWITCH_SPDT_OS102011MA1QN1
SJ1: closed; SJ_2S-TRACE2
SJ2: open; SJ_2S-NO
TP1, TP3, TP4, TP5, TP6, TP7, TP8, TP9, TP10, TP11: PTR1PAD1-13; P1-13
TP2, TP12, TP13, TP14, TP15, TP16, TP17, TP18, TP19, TP20, TP21, TP22, TP24, TP25, TP26: PTR1B1,27; B1,27
TP27: PTR1PAD1-13Y; P1-13Y
TX: M01PTH; 1X01
U1: CN3065-1320040P1; DFN8
U2: ATmega32u4; QFN-44_50P_N
U3: IP4220CZ6; SOT95P275X110-6N
U4: MMA8453Q; QFN-16_0.5MM
U5: CJ1117-3.3-1310120P1; SOT89
U6: CC3000
U7: SHT21; SHT2X
U$1, U$2, U$3: FIDUCIAL; FIDUCIAL_1MM
X1: CRYSTAL-0500290P1; 2P-SMD-5.0X3.2

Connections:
5V_DIRTY: C14.+ (1), C15.+ (1), C17.1, C18.1, C21.1, D1.-, IC3.2 (OUT), L5.1, Q2.2 (S), Q4.2 (S), Q5.2 (S), Q6.3 (D), R3.2, R6.5 (2), R6.6 (2), R6.7 (2), TP4.TP, U5.3 (IN)
5V_FAN: C27.1, C29.+ (1), D2.-, D5.-, JP3.2, Q6.2 (S), R3.1, TP7.TP
!RESET!: JP1.6, K1.0A (A0), K1.1A (A1), U2.13 (!RESET!)
+3V3: C12.2, C16.1, C19.2, C20.2, R15.2, R16.2, R17.1, TP6.TP, U4.1 (VDDIO), U4.14 (VDD), U5.2 (OUT), U5.4 (OUT), U6.P$19 (VBAT_IN), U6.P$23 (VIO_HOST)
+5V: C7.1, C8.1, C23.1, C31.+ (1), J3.3, JP1.4, JP2.P$6 (6), L2.2, L5.2, R8.2, R18.2, TP5.TP, U2.2 (UVCC), U2.14 (VCC), U2.34 (VCC)
CHARGING: TP19.TP, U1.7 (CHRG)
CHRG_DONE: TP20.TP, U1.6 (DONE), U2.1 ((INT6/AIN0)PE6)
D+: J1.3 (DP), R5.2, U3.1 (I/O_4)
D+_MCU: R5.1, U2.4 (D+)
D-: J1.2 (DM), R4.2, U3.6 (I/O_2)
D-_MCU: R4.1, U2.3 (D-)
GND: BAT-.1, C1.2, C2.2, C3.2, C4.2, C5.2, C6.1, C7.2, C8.2, C9.1, C10.2, C11.1, C12.1, C13.2, C14.- (2), C15.- (2), C16.2, C17.2, C18.2, C19.1, C20.1, C21.2, C22.2, C23.2, C24.2, C25.2, C26.2, C28.- (2), C29.- (2), C31.- (2), D3.2 (CATHODE), D4.2 (CATHODE), IC1.P$6 (GND), IC3.4 (GND), J1.5 (GND), J1.E1 (GND), J1.E2 (GND), J1.P1 (GND), J1.P2 (GND), J2.2 (-), J3.4, J3.SS1, J3.SS2, JP1.2, JP1.10, JP2.P$2 (2), JP2.P$4 (4), K1.0B (B0), K1.1B (B1), Q1.2 (S), Q3.2 (S), R1.2, R2.5 (2), R6.8 (2), R13.5 (2), R13.7 (2), R14.5 (2), R14.7 (2), SJ2.1, TP10.TP, TP27.TP, U1.1 (TEMP), U1.3 (GND), U1.HEAT (H), U2.5 (UGND), U2.15 (GND), U2.23 (GND), U2.35 (GND), U2.43 (GND), U3.2 (GND), U4.5 (GND), U4.7 (SA0), U4.10 (GND), U4.12 (GND), U5.1 (GND), U6.P$1 (GND), U6.P$9 (GND), U6.P$10 (GND), U6.P$11 (GND), U6.P$16 (GND), U6.P$18 (GND), U6.P$20 (GND), U6.P$21 (EXT_32K), U6.P$22 (GND), U6.P$25 (GND), U6.P$31 (GND), U6.P$32 (GND), U6.P$33 (GND), U6.P$34 (GND), U6.P$36 (GND), U6.P$37 (GND), U6.P$38 (GND), U6.P$39 (GND), U6.P$40 (GND), U6.P$41 (GND), U6.P$42 (GND), U6.P$43 (GND), U6.P$44 (GND), U6.P$45 (GND), U6.P$46 (GND), U7.0 (VSS), U7.2 (VSS)
GP2_LED: JP2.P$3 (3), U2.25 ((ICP1/ADC8)PD4)
GP2_OUT: JP2.P$5 (5), TP11.TP, U2.26 ((T1/!OC4D!/ADC9)PD6)
INT1: TP21.TP, U2.28 ((PCINT4/ADC11)PB4), U4.11 (INT1)
INT2: TP22.TP, U2.31 ((OC3A/!OC4A!)PC6), U4.9 (INT2)
unnamed: R1.1, U1.2 (ISET)
unnamed: D6.-, F1.1, Q7.2 (S)
unnamed: D1.+, L1.P$2 (2), Q3.3 (D)
unnamed: C11.2, U4.2 (BYP)
unnamed: C3.1, U2.6 (UCAP)
unnamed: C4.1, U2.17 (XTAL1), X1.1
unnamed: C5.1, U2.16 (XTAL2), X1.2
unnamed: C6.2, C10.1, L2.1, U2.24 (AVCC(ADC8-13)), U2.44 (AVCC(ADC0-7))
unnamed: IC3.5 (EXT), Q3.1 (G)
unnamed: U6.P$27 (SDA_EEPROM), U6.P$28 (SDA_CC3000)
unnamed: C9.2, U2.42 (AREF)
unnamed: F1.2, S1.2
unnamed: R2.1, R2.2 (1)
unnamed: R2.6 (2), R2.7 (2)
unnamed: R2.3 (1), R2.4 (1)
unnamed: U6.P$29 (SCL_EEPROM), U6.P$30 (SCL_CC3000)
unnamed: Q5.3 (D), R12.1
unnamed: Q4.3 (D), R10.1
unnamed: Q2.3 (D), R9.1
unnamed: C27.2, D2.+, JP3.1, Q1.3 (D)
unnamed: C28.+ (1), JP2.P$1 (1), R7.1
unnamed: C22.1, R19.2, U2.40 ((ADC1)PF1)
unnamed: R7.2, R8.1
unnamed: C24.1, IC1.P$5 (VCORE)
unnamed: TX.1, U6.P$6 (WL_RS232_TX)
unnamed: SJ1.2, U6.P$7 (WL_EN1)
unnamed: SJ1.1, SJ2.2, U6.P$5 (WL_EN2)
unnamed: RX.1, U6.P$8 (WL_RS232_RX)
unnamed: ANT1.1, U6.P$35 (RF_ANT)
unnamed: D3.4 (BLUE_CATHODE), D4.4 (BLUE_CATHODE), R9.2
unnamed: D3.3 (GREEN_CATHODE), D4.3 (GREEN_CATHODE), R10.2
unnamed: R11.1, R12.2
unnamed: D3.1 (RED_CATHODE), D4.1 (RED_CATHODE), R11.2
unnamed: R14.3 (1), R14.4 (1), U6.P$12 (SPI_CS)
unnamed: R14.1, R14.2 (1), U6.P$15 (SPI_DIN)
unnamed: R13.3 (1), R13.4 (1), U6.P$17 (SPI_CLK)
unnamed: R13.1, R13.2 (1), U6.P$26 (VBAT_SW_EN)
unnamed: TP2.TP, U2.33 ((!HWB!)PE2)
PWM_B: Q2.1 (G), R6.4 (1), TP14.TP, U2.27 ((T0/OC4D/ADC10)PD7)
PWM_G: Q4.1 (G), R6.3 (1), TP13.TP, U2.29 ((PCINT5/OC1A/!OC4B!/ADC12)PB5)
PWM_MOTOR: Q1.1 (G), R6.1, TP15.TP, U2.32 ((ICP3/CLK0/OC4A)PC7)
PWM_R: Q5.1 (G), R6.2 (1), TP12.TP, U2.30 ((PCINT6/OC1B/OC4B/ADC13)PB6)
SCL_3.3V: IC1.P$4 (SCL), J3.1, R16.1, TP9.TP, U2.18 ((OC0B/SCL/INT0)PD0), U4.4 (SCL), U7.6 (SCL)
SDA_3.3V: IC1.P$3 (SDA), J3.2, R15.1, TP8.TP, U2.19 ((SDA/INT1)PD1), U4.6 (SDA), U7.1 (SDA)
TCK: JP1.1, U2.39 ((ADC4/TCK)PF4)
TDI: JP1.9, U2.36 ((ADC7/TDI)PF7)
TDO: JP1.3, U2.37 ((ADC6/TDO)PF6)
TMS: JP1.5, U2.38 ((ADC5/TMS)PF5)
VBAT: BAT+.1, C2.1, J2.1 (+), Q7.3 (D), R19.1, U1.5 (BAT), U1.8 (FB)
VRAW: C13.1, IC3.1 (CE), L1.P$1 (1), S1.3, TP3.TP, U2.41 ((ADC0)PF0)
VUSB: C1.1, D5.+, D6.+, J1.1 (VCC), Q6.1 (G), Q7.1 (G), R2.8 (2), TP1.TP, U1.4 (VIN), U2.7 (VBUS), U3.5 (VP)
V_TEMP: C25.1, C26.1, IC1.P$7 (VDD), R17.2, R18.1, U7.5 (VDD)
WIFI_CS: R14.6 (2), TP17.TP, U2.21 ((TXD1/INT3)PD3)
WIFI_ENABLE: R13.8 (2), TP16.TP, U2.8 ((SS/PCINT0)PB0)
WIFI_IRQ: TP18.TP, U2.20 ((RXD1/INT2)PD2), U6.P$14 (SPI_IRQ)
WIFI_MISO: TP26.TP, U2.11 ((PDO/PCINT3/MISO)PB3), U6.P$13 (SPI_DOUT)
WIFI_MOSI: R14.8 (2), TP25.TP, U2.10 ((PDI/PCINT2/MOSI)PB2)
WIFI_SCK: R13.6 (2), TP24.TP, U2.9 ((PCINT1/SCLK)PB1)

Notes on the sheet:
Power
Note: charge current is 500mA@Rprog=3.6k, 900mA@Rprog=2k. (Formula: I_chrg = 1800/R)
CHARGING, CHRG_DONE must use internal pull ups
Connectors
WiFi module
USB stuff
I2C addr is 0x1C (SA0=0)
Accel (tilt sensor)
Normal: SJ1 closed & SJ2 open Test: SJ1 open & SJ2 closed
SHT21: Polulate R17, NOT R18, NOT C26, NOT C24.
Temp/Humidity Sensor
Use either SHT21 or CC2D23 or CC2D25.
Fan Motor
5V_Dirty: input for 3.3v reg, LEDs, fan.
PM sensor
LEDs
CAUTION: antenna design is not the one recommended. No automatic FCC approval, and no certainty of signal quality.
DO NOT USE INTERNAL PULL-UP FOR I2C!
I2C pull ups
CAUTION Blue and Green are swaped in reality!
Dropout voltage is <=1.3V, so input has to be at least 4.6V => we can't trust VUSB with that, so we use 5V_DIRTY and never VUSB.
5V_FAN is between 4.1V and 4.7V when connectd in USB, 5V otherwise. If more constant value is needed, unpopulate Q6 and D5, and populate R3.
Pull-down for Q6 and Q7
Fiducials
CC2D23: Populate R17, NOT R18
CC2D25: Populate R18, NOT R17
Airboxlab v2.2
CC-BY-SA
(c) Airboxlab S.A.

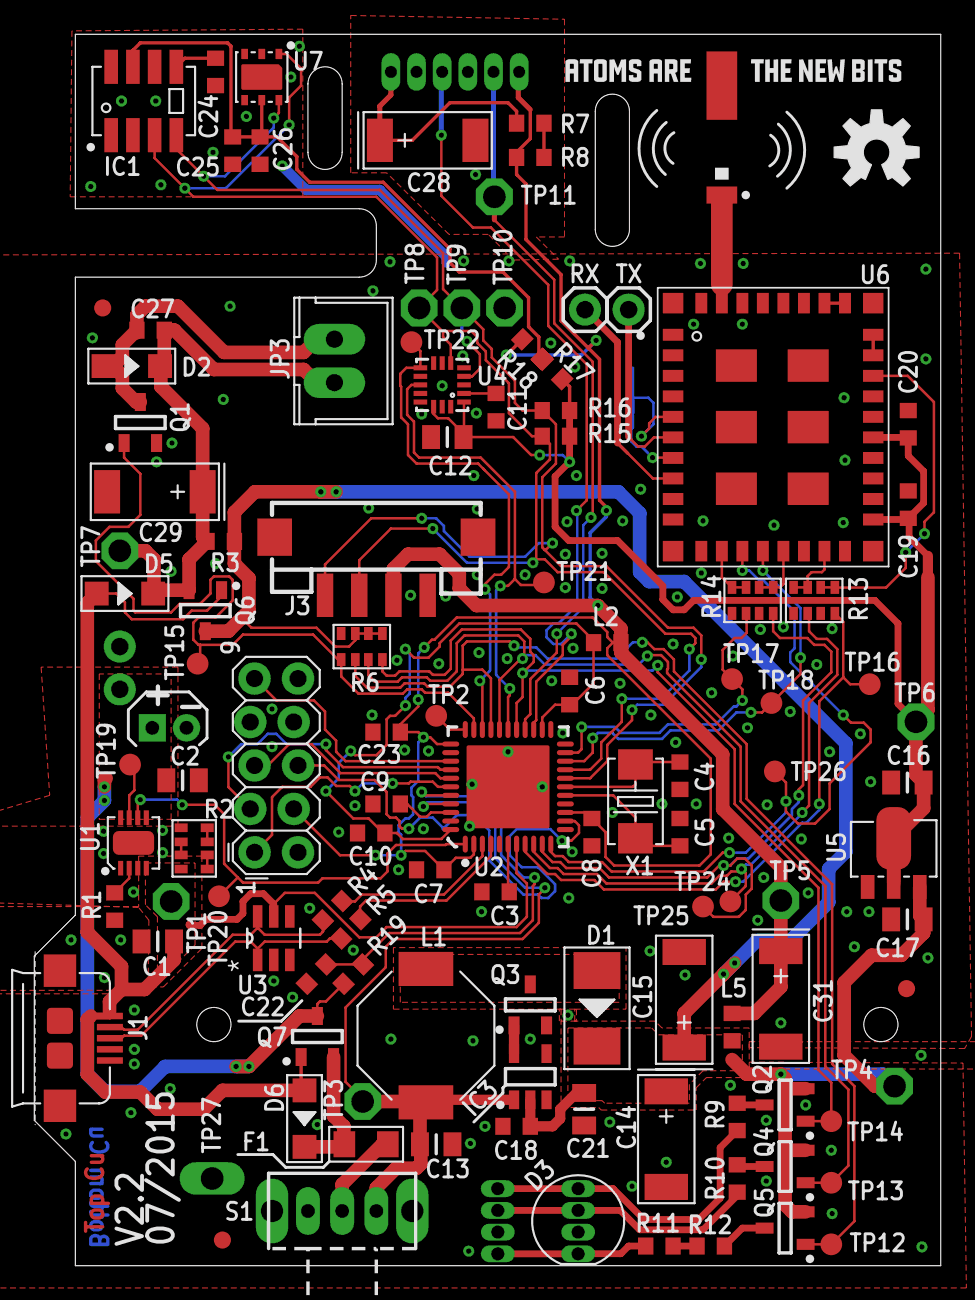
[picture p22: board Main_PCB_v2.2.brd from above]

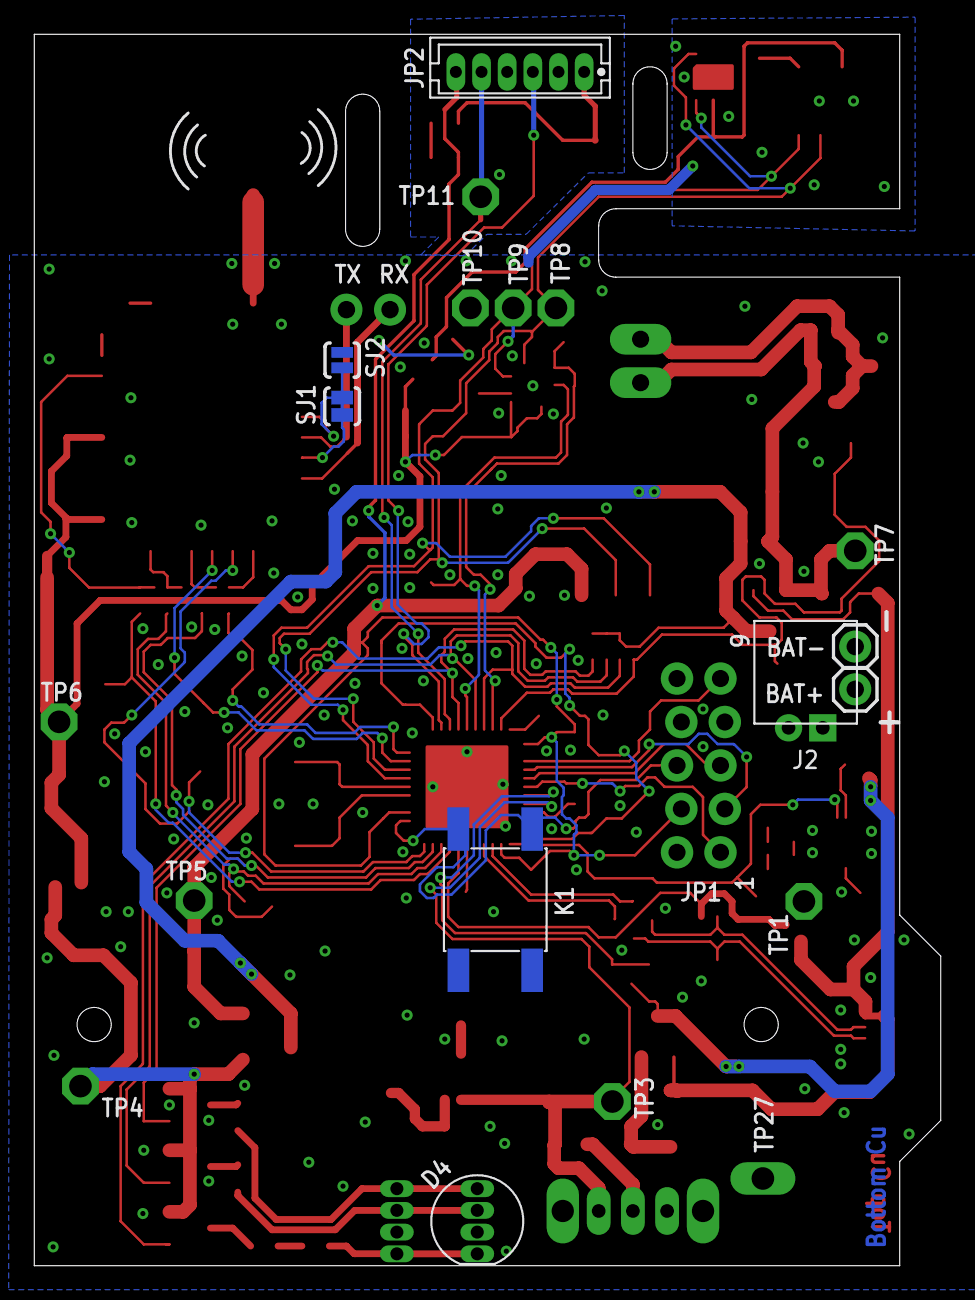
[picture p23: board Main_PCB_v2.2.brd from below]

Board: 2 copper layers, 53.0 x 72.0 mm, 121 parts (9 on the bottom side), 74 nets.

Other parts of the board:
U$4: OSHW-LOGO-M

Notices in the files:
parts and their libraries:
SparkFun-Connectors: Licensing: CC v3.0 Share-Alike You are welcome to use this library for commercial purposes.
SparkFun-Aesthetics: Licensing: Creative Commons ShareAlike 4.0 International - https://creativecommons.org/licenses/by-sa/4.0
